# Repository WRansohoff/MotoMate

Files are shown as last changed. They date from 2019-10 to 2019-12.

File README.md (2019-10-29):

# "MotoMate" Handheld GPS Receiver

This is a small board designed to act as a handheld GPS receiver, and eventually (I hope) a handlebar-mounted GPS mapper / tracker for offroad motorcycling.

# Details

The microcontroller core is an STM32L496Rx chip - I recommend the STM32L496RGT3, because it costs less than $1 to get an extra 512KB of Flash (although the chip itself is more like $10). The 320KB of built-in RAM is enough to store a 150KB framebuffer for the 320x240 16bpp ILI9341 display, but it doesn't leave much room for storage-intensive algorithms such as image processing. Still, there's no external storage to worry about besides the microSD card.

The board is wired to use hardware periphererals for driving the SD/MMC interface, USB OTG, SPI for the display, and UART for talking to a "GY-NEO6MV2" GPS module. I've noticed that some listings for these u-blox Neo-6M-based GPS modules have red-colored boards with pinouts that won't work with this design; look for blue-colored ones and double-check the pinouts against the schematic. I might update the design to use the module itself instead of a cheap breakout board in the future, but for now, sorry for the inconvenience.

There's also a single-channel audio amplifier connected to one of the chip's DACs with a mute switch, and some ADCs are used to monitor a photodiode and the board's battery voltage. And there are pads exposed for an extra UART and I2C connection, and seven button inputs split across two tactile buttons and a 'navigation switch'. The buttons are assigned to pins so that there shouldn't be any conflicts with EXTI lines when setting up interrupts to listen for presses.

I'll write up more comprehensive information (and upload some proper gerber files) once I've had a chance to test this revision and upload some basic test firmwares to confirm the board's various functions.

# Schematic and Board Renders

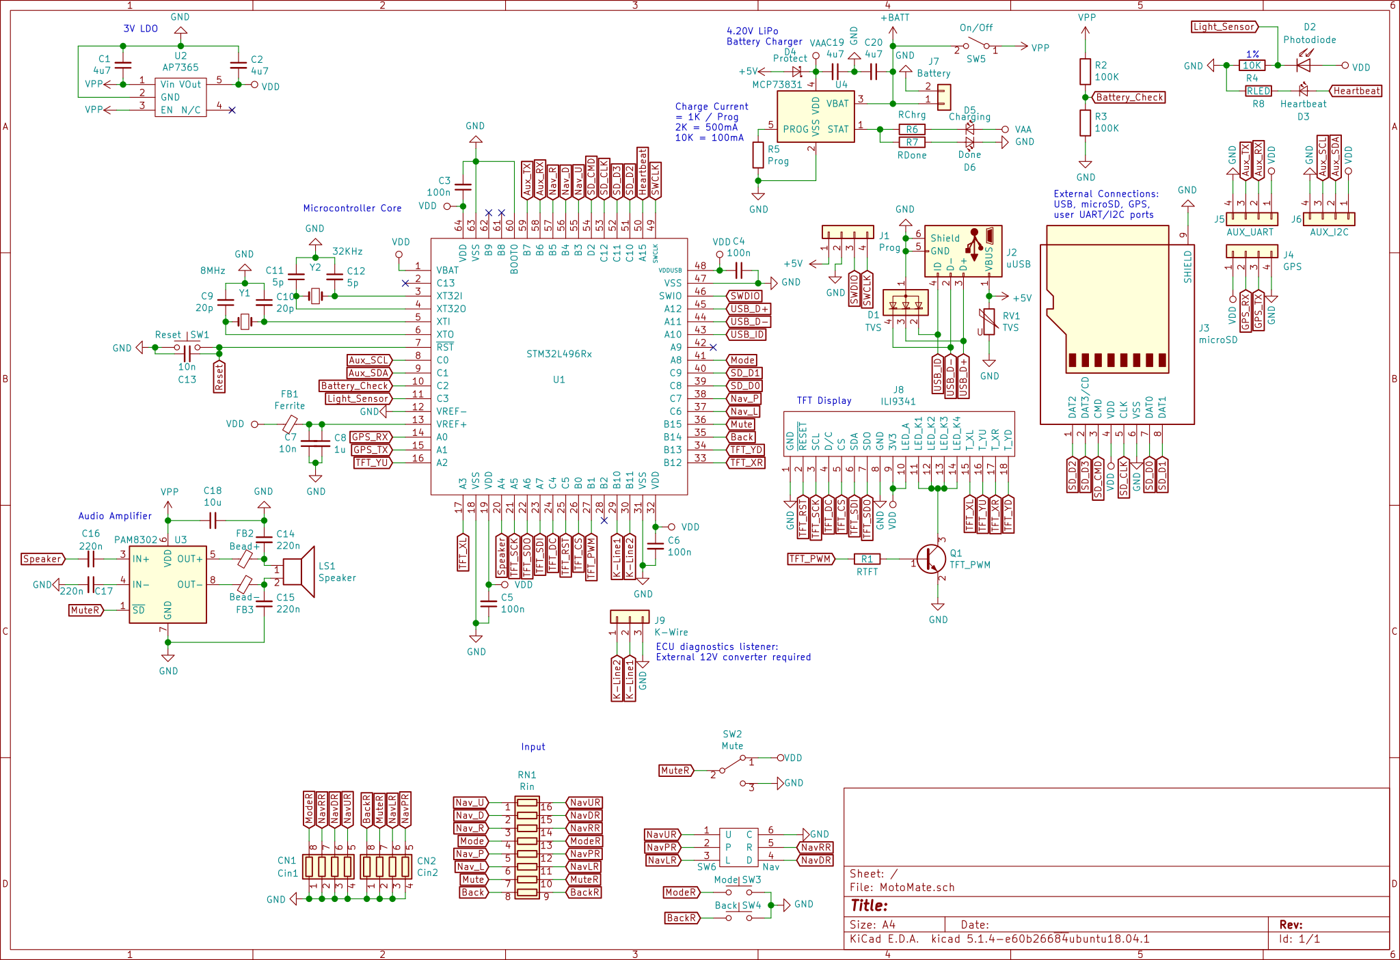
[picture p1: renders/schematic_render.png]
Schematic


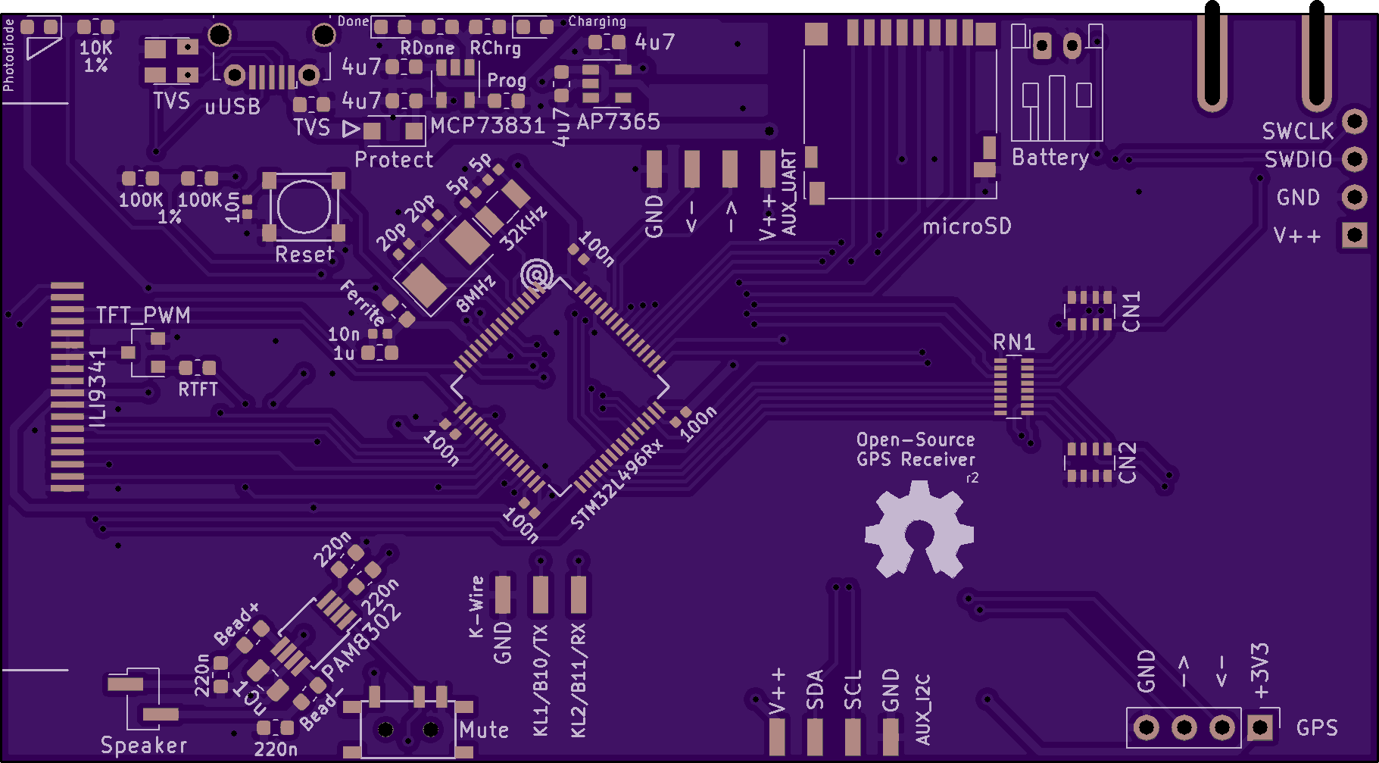
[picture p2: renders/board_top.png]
Board Top


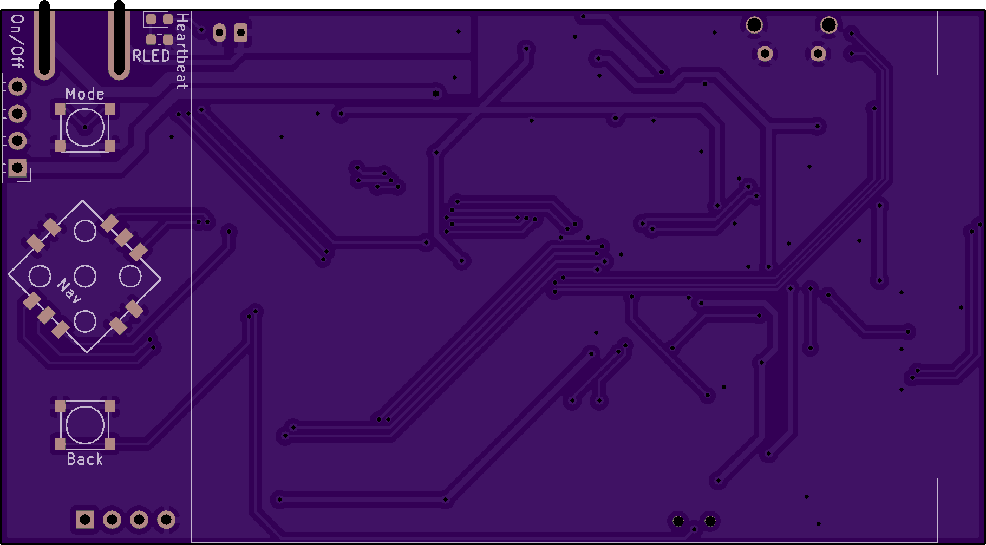
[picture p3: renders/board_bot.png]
Board Bottom


# Previous Revision

I've assembled an earlier version of this design and confirmed that most parts of the design work, but I haven't written a comprehensive "GPS mapper" firmware yet. The first version has too much space between the TFT ribbon connector and the edge of the board to fold the display over the USB connector and mute switch, so it was awkward to handle. I hope that this version will fit together better, but I haven't received it yet for testing.

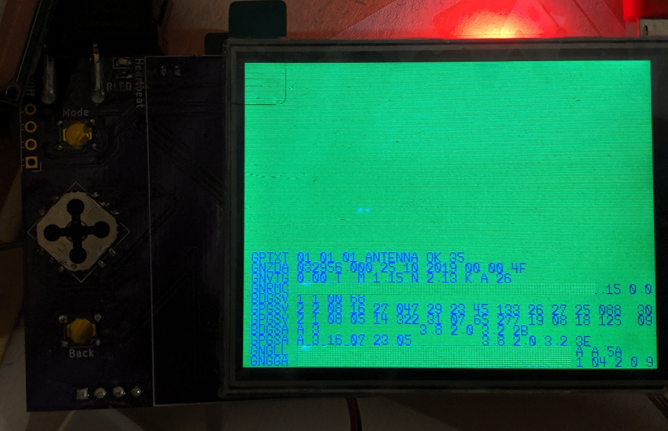
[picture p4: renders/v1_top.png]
V1 Top


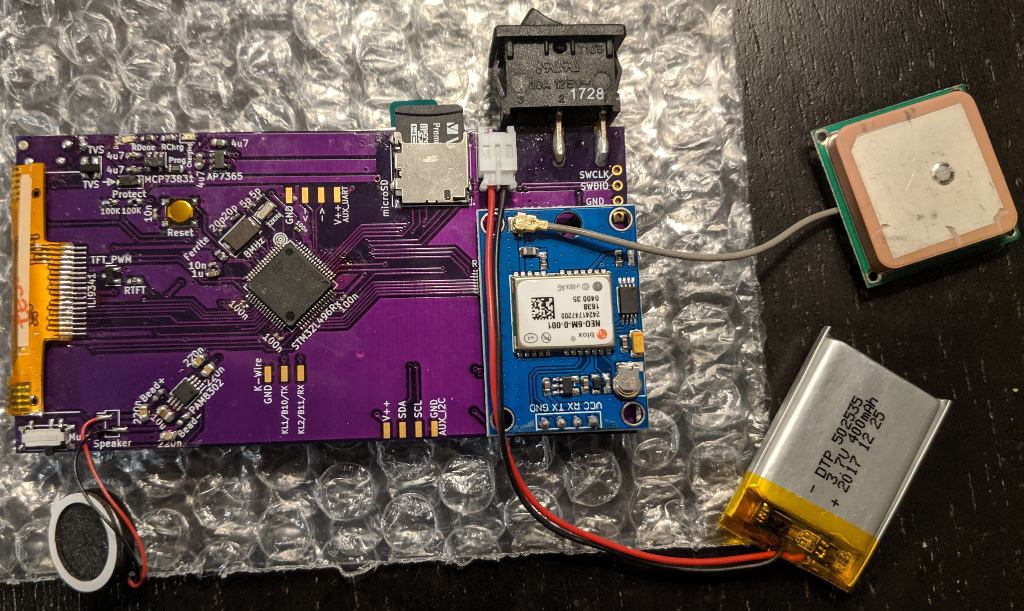
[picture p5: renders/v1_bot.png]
V1 Bottom


Sorry that I didn't get a better picture of the lit-up TFT; it's hard to take pictures of backlit displays, and it's not that important anyways. I also edited one of the images to remove the actual GPS coordinates, because I didn't feel like driving out to the middle of the woods to take a picture.

Anyways, so far I've tested (or not) the following parts:

* Battery monitoring: the 'charging' and 'done' LEDs seem to reflect the charge status, and the 12-bit ADC reads close to 4.2V on a full charge using the formula: `VBatt = ( ADC * 2 / 4095 ) * 3.3`. Note that for an accurate reading, you need to set one of the highest sampling times (250-650 cycles) due to the low amount of current flowing through the voltage divider.

* TFT display: The backlight can be adjusted with a PWM signal, and the SPI peripheral can be used with DMA to draw a framebuffer to the display. This makes it much easier to test other parts of the board :)

* GPS module: Appears to work, although I haven't tried configuring it with anything other than the default settings. After placing the antenna with a clear view of the sky and letting it acquire a few satellites, it reports latitude and longitude readings that appear to be accurate to within maybe 5 meters or so.

* microSD card: Not tested.

* Buttons: Tested using falling-edge interrupts with the pins configured as inputs with pull-up resistors enabled. These low-profile buttons are really designed to be used with a case that has plastic or rubber 'pegs' connected to larger buttons, though.

* Auxiliary UARTs and I2C: Not tested.

* 'Heartbeat' LED: Works.

* Photodiode: Not tested; in the first revision of the board, I put the photodiode underneath where the display's ribbon connector folded over, so it was always in darkness. D'oh!

* Speaker: Works well enough to play a sine wave accurately enough for a tuner to read the desired note. I haven't tried playing music or speech though, and it probably wouldn't do that very well. This is only a 12-bit DAC with poor filtering, after all. The speaker is mostly intended for beeps, buzzes, and chirps.

See `firmware/` for the source code used to run those tests, and `fw_lib/` for some shared helper functions.

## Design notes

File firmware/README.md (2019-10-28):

# Test Firmwares

These projects test various parts of the board. The directories are named after the functionality that a project tests. These use shared functionality from the libraries located under `../fw_lib/`.

The `v1_testsuite` project is an attempt to pull all of these examples into one firmware image which lets the user test each part of the board from a menu, although that will depend on the display and buttons working. It's a work-in-progress, but so is this entire repository.

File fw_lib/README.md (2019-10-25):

# Firmware Libraries

These directories include simple supporting libraries for parts that are mounted to the board. It might be re-inventing the wheel a bit, but these simple files should at least be enough to test that the board works.

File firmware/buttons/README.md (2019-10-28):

# Buttons Test

This project initializes the display, and sets up hardware interrupts for each of the 7 buttons. When a button is pressed, the display's background color will be changed.

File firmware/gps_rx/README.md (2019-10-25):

# GPS Reception Test

This project initializes the display and the UART connected to the GPS module, and draws the NMEA data received from the GPS module to the display. It's hard to read the raw data, but once enough satellites are acquired, it should print out the latitude and longitude in a fairly easy-to-parse format.

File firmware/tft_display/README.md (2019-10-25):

# TFT Framebuffer Test

This project tests using DMA and SPI to draw a framebuffer to the TFT display. It tests the various framebuffer drawing method, and flashes back and forth between colors to get a feel for the refresh rate. It looks pretty responsive, but I don't have any numbers yet.

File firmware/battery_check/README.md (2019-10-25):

# Battery Check

This project verifies that the board can read its own battery voltage. It initializes the display and the appropriate ADC channel, then it reads the channel and prints the raw ADC value to the display.

# TODO

I need to add a 'draw float' method to my simple framebuffer library, so that the example can draw an estimated voltage instead of the raw ADC value.

`VBatt = ( ADC * 2 / 4095 ) * VReg`

Where `VBatt` is the battery voltage and `VReg` is the regulated supply voltage. `VReg` is probably 3.3V, but sometimes I use 3V.

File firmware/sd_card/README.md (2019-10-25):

# SD Card test

This project is still a work-in-progress; right now I think it just flashes the display between two colors.

I'd like for it to test the microSD card slot, but I'm not there yet.

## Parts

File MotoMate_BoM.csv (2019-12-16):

Part ID | Part type | Part size (Imperial) | Part value | Example Digikey Item | Cost (qty: x) | Comment
C1, C2, C19, C20 | Capacitor | 0603 | 4.7 μF | https://www.digikey.com/short/p2hdqt | $0.68 | Power supply decoupling capacitors for voltage regulator and battery charger. Use X5 or X7 ceramic capacitors rated for at least 6.3V (for 5V voltage inputs)
C3, C4, C5, C6 | Capacitor | 0402 | 100 nF | https://www.digikey.com/short/p2hrz2 | $0.40 | Decoupling capacitors for the microcontroller / etc. Prefer X5 or X7 ceramic capacitors.
C7, C13 | Capacitor | 0402 | 10 nF | https://www.digikey.com/short/p2hr54 | $0.20 | Decoupling capacitors for the reset button and analog voltage supply. Use X7 ceramic capacitors.
C8 | Capacitor | 0603 | 1 μF | https://www.digikey.com/short/pdhnbv | $0.10 | Decoupling capacitor for the analog voltage supply. Use X7 ceramic capacitors.
C9, C10 | Capacitor | 0402 | 20 pF | https://www.digikey.com/short/pdhnbj | $0.20 | Decoupling capacitors for the high-speed external oscillator crystal. Actual values will depend on your crystal; 20pF is a rough estimate. Use C0G / NP0 ceramic capacitors.
C11, C12 | Capacitor | 0402 | 5 pF | https://www.digikey.com/short/pdhnbc | $0.20 | Decoupling capacitors for the low-speed external oscillator crystal. Actual values will depend on your crystal; 5pF is a rough estimate. Use C0G / NP0 capacitors.
C16, C17 | Capacitor | 0603 | 220 nF | https://www.digikey.com/short/pdhnhv | $0.20 | Filtering capacitors for the audio amplifier's input and output. Use X7 ceramic capacitors.
C18 | Capacitor | 0805 | 10 μF | https://www.digikey.com/short/pdhn55 | $0.13 | Power supply decoupling capacitor for the audio amplifier. Use X5 or X7 ceramic capacitors.
CN1, CN2 | Capacitor Network | 0612 | 10 nF | https://www.digikey.com/short/pdhr2m | $0.64 | Capacitor arrays for various debouncing filters. Values aren't too important; it's just to help prevent the microcontroller from incorrectly registering spurious button presses.
D1 | TVS Diode Network | SOT-143-4 | SP0503 | https://www.digikey.com/short/pdhfqd | $0.82 | 3-in-1 TVS diodes for USB data line filtering. These diodes should protect the two differential data lines and the OTG 'ID' line.
D2 | Photodiode | 0603 | ALS-PT19 | https://www.digikey.com/short/pdhfq3 | $0.43 | Photodiode for detecting ambient light levels. I hope this can be used for automatic brightness adjustment.
D3 | LED | 0603 | Any Color | https://www.digikey.com/short/p2hdpf | $0.14 | Heartbeat' LED, for basic testing and blinking.
D4 | Schottky Diode | SOD-123 | >= 10V, 1A | https://www.digikey.com/short/pdhw7b | $0.33 | Schottky diode to protect against reverse polarity.
D5 | LED | 0603 | Red | https://www.digikey.com/short/pdh21f | $0.14 | "Charging" LED, lit up when the battery is charging.
D6 | LED | 0603 | Green | https://www.digikey.com/short/pdh21m | $0.14 | "Done" LED, lit up when the battery has finished charging.
FB1 | Ferrite Bead | 0603 | N/A | https://www.digikey.com/short/p2h080 | $0.10 | Ferrite bead for filtering noise out of the analog voltage supply.
FB2, FB3 | Ferrite Bead | 0603 | N/A | https://www.digikey.com/short/p2h080 | $0.20 | Ferrite beads for filtering the audio amplifier's differential output.
J1 | Pin Header | 0.1" | 1x4 | https://www.digikey.com/short/pdhw3q | $0.13 | Programming / debugging header.
J2 | USB Connector | Micro-B Socket | N/A | https://www.digikey.com/short/pdhw81 | $2.07 | Micro-USB connector for battery charging and USB communication. I'm still working through a reel of cheap-o micro-B sockets that I ordered awhile ago, but they seem to fit the "Wuerth_629105150521" footprint in KiCAD.
J3 | MicroSD Connector | Socket | Hirose DM3D-SF | https://www.digikey.com/short/pdh2z2 | $1.75 | MicroSD card socket, for storing maps / images / routes / logs / etc.
J4 | Pin Header | 0.1" | 1x4 | https://item.taobao.com/item.htm?id=40580284168 | $2.50 | GPS breakout connector for a generic 4-pin uBlox Neo-6m GPS breakout board. This project is designed to fit a blue-colored "GY-NEO6MV2" breakout board, which is a cheap module that is widely available on eBay / Amazon / AliExpress / TaoBao / etc. These modules are much cheaper from Eastern listings than from Western ones. I've noticed that red-colored versions of this GPS module seem to have a different pinout that won't fit, so double-check the module's silkscreen markings against this project's schematic before you order one. Sorry that I can't link to a more reliable source; I can't endorse any particular third-party marketplace seller, including the one linked to here, and ordering from eBay-style sellers is never a completely sure bet. Maybe in the future I'll try to integrate the ublox module itself on the board.
J5, J6 | Pin Header | 0.1" | 1x4 | N/A | $0.00 | Flat single-side connectors for auxiliary UART and I2C add-ons. Optional.
J7 | JST Connector | PH-2 | 1x2 | https://www.digikey.com/short/pdh24c | $0.17 | Battery connector - the JST PH-2 connector is popular among small lithium batteries, such as those sold by Adafruit. Double-check the polarity!
J8 | Flex Ribbon Connector | 0.8 mm | 1x18 | https://item.taobao.com/item.htm?id=540901079780 | $3.33 | Connector for an 18-pin / 0.8mm-pitch 2.8" ILI9341 SPI TFT display with a resistive 'touch screen' overlay. These are cheap and widely-available from places like eBay / AliExpress / TaoBao / etc. DigiKey doesn't carry them, but using surplus 'off-brand' displays often saves about $10-20 per board for us hobbyists. Double-check the pinout against the listing you buy from, and consider using a different vendor or a forwarding service if you aren't familiar with ordering from TaoBao.
J9 | Pin Header | 0.1" | 1x3 | N/A | $0.00 | Flat single-side 3-pin connector for adding a "K-Wire" interface board later on. My motorcycle uses this old standard which predates OBD-II, and while it is a 12V single-wire protocol, I hope to eventually make an adapter board which isolates 'transmit' and 'receive' signals for use with a UART peripheral.
LS1 | Speaker | 2-Wire | 4 Ω | https://www.digikey.com/short/pdhnmp | $2.35 | Speaker for the single-channel audio amplifier output.
Q1 | Transistor | SOT-23 | NPN, BEC | https://www.digikey.com/short/pdhf4v | $0.12 | Transistor to control the TFT display's backlight brightness using PWM.
R1 | Resistor | 0603 | 1 KΩ | https://www.digikey.com/short/p2hdw9 | $0.10 | Base resistor for the TFT backlight control transistor. Value doesn't matter too much, keep it in the range of about 100Ω - 10KΩ
R2, R3 | Resistor | 0603 | 100 KΩ, 1% | https://www.digikey.com/short/pdh2b7 | $0.10 | Resistors for the voltage divider which lets the microcontroller read its own battery voltage. Use resistors with 1% precision, or choose two which have almost identical values.
R4 | Resistor | 0603 | 10 KΩ | https://www.digikey.com/short/pdh29r | $0.10 | Resistor which lets the microcontroller read an analog voltage from its photodiode input. Prefer resistors with 1% precision, but you'll probably have to calibrate the brightness reading anyways since photodiodes aren't very precise.
R5 | Resistor | 0603 | >= 2 KΩ, 1% | https://www.digikey.com/short/pdh2b4 | $0.10 | This resistor sets the rate of charge for the battery charger. Charge current = 1000 / R, so use 2KΩ for a 500mA charge rate, 10KΩ for a 100mA charge rate, etc. 500mA is the maximum charge rate. Use resistors with 1% precision to ensure you get the right charge rate.
R6, R7, R8 | Resistor | 0603 | 220Ω - 4.7KΩ | https://www.digikey.com/short/p2hdw9 | $0.30 | Current-limiting resistors for the "charging", "done charging", and "heartbeat" LEDs. Use higher values to make the LEDs dimmer.
RN1 | Resistor Network | 1506 | 1 KΩ | https://www.digikey.com/short/pdhr1z | $0.29 | Resistor array for various debouncing filters. Value isn't too important; it's just to help prevent the microcontroller from reading spurious button presses.
RV1 | Varistor | 0603 | 5.5V (7.1V-9.3V) | https://www.digikey.com/short/pdhrv3 | $0.48 | TVS varistor for the +5V power line. It should serve a similar function to the TVS diodes on the data lines, protecting the system from Transient Voltage surges.
SW1 | Tactile Button | SMD | SPST | https://www.digikey.com/short/pdhr0w | $0.22 | Reset button.
SW2, SW5 | Slide Switch | SMD | SPDT | https://www.digikey.com/short/pd2qtz | $1.82 | "Mute" switch for the speaker, and power on/off switch.
SW3, SW4 | Tactile Button | SMD | SPST | https://www.digikey.com/short/pdhr0w | $0.44 | "Mode" and "Back" tacticle buttons (user input).
SW6 | Navigation Switch | SMD | 5-Direction | https://www.digikey.com/short/pdhr0h | $2.38 | "Navigation switch" for user input. It has four directional buttons and one "press" button, plus a common pin which I connected to ground.
U1 | Microcontroller | QFP-64 (10x10 mm) | STM32L496 | https://www.digikey.com/short/pdhrd8 | $10.99 | Microcontroller core. The STM32L496Rx is available with either 512KB or 1MB of Flash memory. "-T6" suffix is rated to 85C, "-T3" to 125C. The 1MB / 125C version is less than $1 more expensive than the 512KB / 85C one, so I linked to the better one.
U2 | Voltage Regulator | DFN-6 (2x2 mm) | LDFM33 | https://www.digikey.com/short/p1r27t | $0.75 | Main voltage regulator.
U3 | Audio Amplifier | MSOP-8 (3x3 mm) | PAM8302A | https://www.digikey.com/short/pdhwt9 | $0.63 | Simple 2.5W mono audio amplifier. Mostly just for beeping and buzzing.
U4 | Battery Charger | SOT-25 | MCP73831 | https://www.digikey.com/short/pdhw7v | $0.56 | Battery charging circuit. I use the 4.2V version with "3.7V nominal / 4.2V charge" lithium batteries.
Y1 | Crystal | 5x3.2 mm | 8 MHz | https://www.digikey.com/short/pdhr1d | $1.14 | "High-Speed External" oscillator crystal. You can use values between 4MHz and 32MHz, but I usually use 8MHz.
Y2 | Crystal | 3.2x1.5 mm | 32.768 KHz | https://www.digikey.com/short/p2h0zh | $0.41 | "Low-Speed External" oscillator crystal.
Total: |  |  |  |  | $38.28 | You can shave a decent amount off this price by using generic connectors / crystals / etc, and by buying capacitors / resistors / diodes / etc in bulk. Just be sure to verify the footprints.

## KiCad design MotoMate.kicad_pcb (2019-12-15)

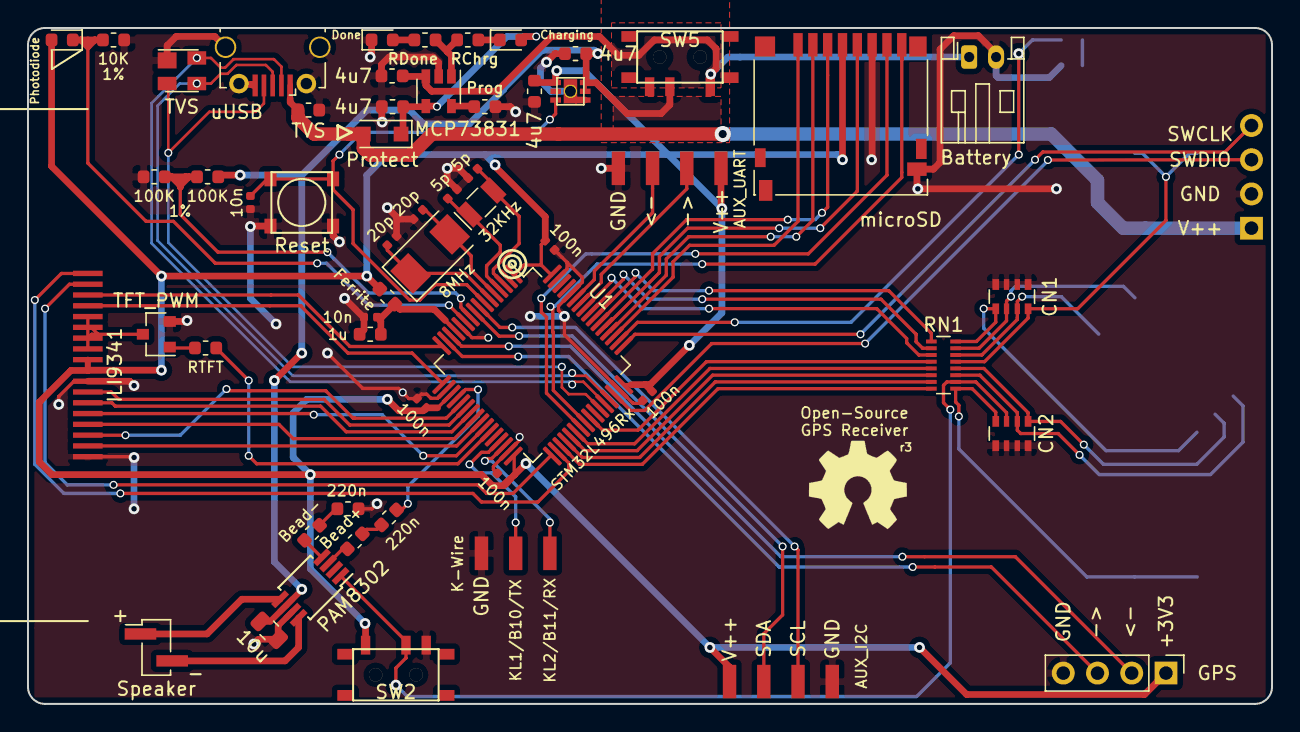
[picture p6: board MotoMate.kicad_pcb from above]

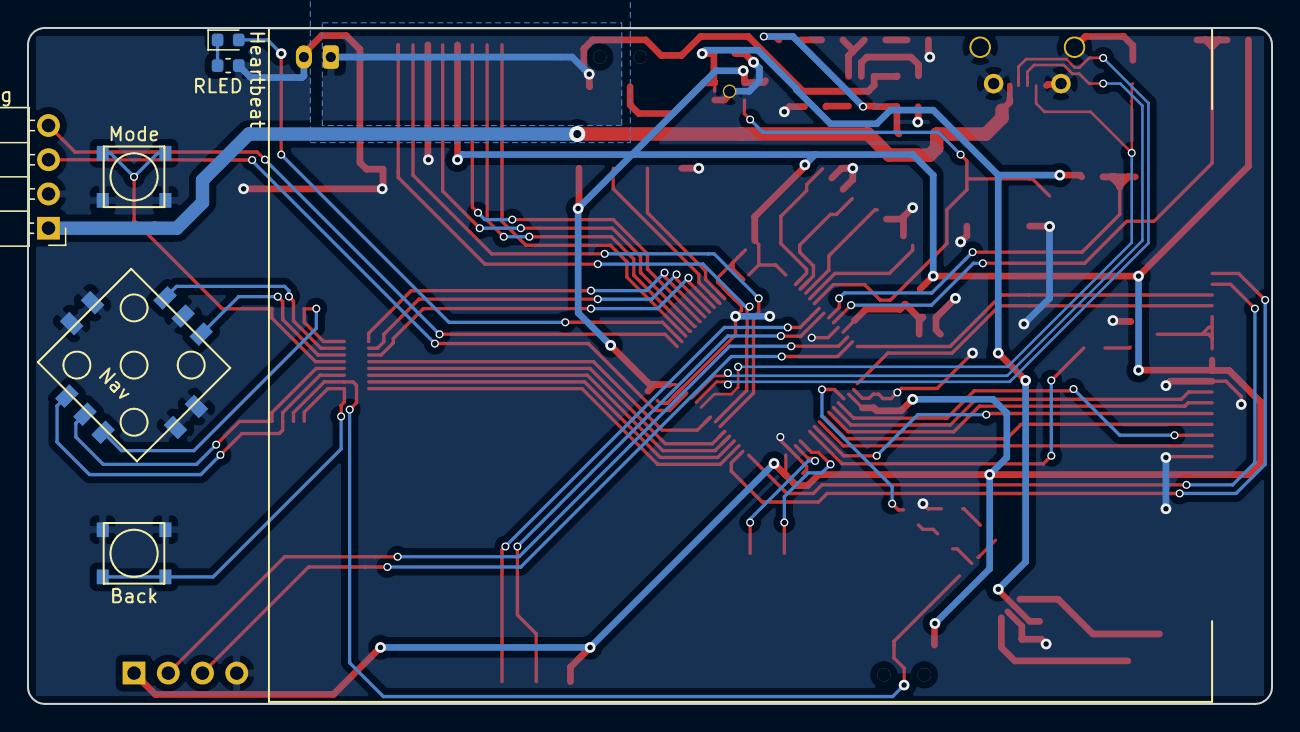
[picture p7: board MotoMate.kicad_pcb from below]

Board: 2 copper layers, 92.3 x 50.2 mm, 62 parts (6 on the bottom side), 75 nets.

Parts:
C1, C2, C19, C20: 4u7; C_0603_1608Metric
C3, C4, C5, C6: 100n; C_0402_1005Metric
C7, C13: 10n; C_0402_1005Metric
C8: 1u; C_0603_1608Metric
C9, C10: 20p; C_0402_1005Metric
C11, C12: 5p; C_0402_1005Metric
C16, C17: 220n; C_0603_1608Metric
C18: 10u; C_0805_2012Metric
CN1: Cin1; R_Array_Convex_4x0603
CN2: Cin2; R_Array_Convex_4x0603
D1: TVS; SOT-143
D2: Photodiode; LED_0603_1608Metric
D3: Heartbeat; LED_0603_1608Metric
D4: Protect; D_SOD-123F
D5: Charging; LED_0603_1608Metric
D6: Done; LED_0603_1608Metric
FB1: Ferrite; R_0603_1608Metric
FB2: Bead+; R_0603_1608Metric
FB3: Bead-; R_0603_1608Metric
J1: Prog; PinHeader_1x04_P2.54mm_Horizontal
J2: uUSB; MyMicroUSB
J3: microSD; microSD_HC_Hirose_DM3D-SF
J4: GPS; PinHeader_1x04_P2.54mm_Vertical
J5: AUX_UART; Conn_01x04_H_SMD
J6: AUX_I2C; Conn_01x04_H_SMD
J7: Battery; JST_PH_S2B-PH-K_1x02_P2.00mm_Horizontal
J8: ILI9341; ILI9341_18P_0.8mm
J9: K-Wire; Conn_01x03_H_SMD
LS1: Speaker; PinHeader_1x02_P2.00mm_Vertical_SMD_Pin1Left
Q1: TFT_PWM; SOT-23
R1: RTFT; R_0603_1608Metric
R2, R3: 100K; R_0603_1608Metric
R4: 10K; R_0603_1608Metric
R5: Prog; R_0603_1608Metric
R6: RChrg; R_0603_1608Metric
R7: RDone; R_0603_1608Metric
R8: RLED; R_0603_1608Metric
RN1: Rin; R_Array_Convex_8x0602
RV1: TVS; R_0603_1608Metric
SW1: Reset; Snap_Tac_Switch_SMT
SW2: Mute; mini_slide_switch
SW3: Mode; Snap_Tac_Switch_SMT
SW4: Back; Snap_Tac_Switch_SMT
SW5: On/Off; mini_slide_switch
SW6: Nav; NavSwitch_SMT
U1: STM32L496Rx; LQFP-64_10x10mm_P0.5mm
U2: LDFM33; ST_LDFM_2x2DFN
U3: PAM8302; MSOP-8_3x3mm_P0.65mm
U4: MCP73831; SOT-23-5
Y1: 8MHz; Crystal_SMD_Abracon_ABM3-2Pin_5.0x3.2mm
Y2: 32KHz; Crystal_SMD_EuroQuartz_EQ161-2Pin_3.2x1.5mm

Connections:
+5V: D4.2, J1.1, J2.1, RV1.1
+BATT: C20.1, J7.1, SW5.1, U4.3
Aux_RX: J5.2, U1.58
Aux_SCL: J6.3, U1.8
Aux_SDA: J6.2, U1.9
Aux_TX: J5.3, U1.59
Back: RN1.8, U1.35
BackR: CN2.8, RN1.9, SW4.1
Battery_Check: R2.1, R3.2, U1.10
GND: C1.2, C2.1, C3.2, C4.1, C5.1, C6.2, C7.1, C8.2, C9.2, C10.1, C11.2, C12.1, C13.2, C17.2, C18.2, C19.1, C20.2, CN1.1, CN1.2, CN1.3, CN1.4, CN2.1, CN2.2, CN2.3, CN2.4, D1.1, D6.1, J1.2, J2.5, J2.6, J3.6, J3.9, J4.4, J5.4, J6.4, J7.2, J8.1, J8.8, J9.3, Q1.2, R3.1, R4.2, R5.2, R8.2, RV1.2, SW1.1, SW2.3, SW3.2, SW4.2, SW6.6, U1.12, U1.18, U1.31, U1.47, U1.60, U1.63, U2.4, U2.7, U3.7, U4.2
GPS_RX: J4.2, U1.14
GPS_TX: J4.3, U1.15
Heartbeat: D3.2, U1.50
K-Line1: J9.2, U1.29
K-Line2: J9.1, U1.30
Light_Sensor: D2.1, R4.1, U1.11
Mode: RN1.4, U1.41
ModeR: CN1.8, RN1.13, SW3.1
Mute: RN1.7, U1.36
MuteR: CN2.7, RN1.10, SW2.2, U3.1
NavDR: CN1.6, RN1.15, SW6.4
NavLR: CN2.6, RN1.11, SW6.3
NavPR: CN2.5, RN1.12, SW6.2
NavRR: CN1.7, RN1.14, SW6.5
NavUR: CN1.5, RN1.16, SW6.1
Nav_D: RN1.2, U1.56
Nav_L: RN1.6, U1.37
Nav_P: RN1.5, U1.38
Nav_R: RN1.3, U1.57
Nav_U: RN1.1, U1.55
unnamed: C7.2, C8.1, FB1.1, U1.13
unnamed: C9.1, U1.6, Y1.1
unnamed: C10.2, U1.5, Y1.2
unnamed: C11.1, U1.4, Y2.1
unnamed: C12.2, U1.3, Y2.2
unnamed: C16.1, FB2.2
unnamed: C17.1, FB3.1
unnamed: D3.1, R8.1
unnamed: D5.1, R6.1
unnamed: D6.2, R7.1
unnamed: FB2.1, U3.3
unnamed: FB3.2, U3.4
unnamed: J8.11, J8.12, J8.13, J8.14, Q1.3
unnamed: LS1.1, U3.5
unnamed: LS1.2, U3.8
unnamed: Q1.1, R1.1
unnamed: R5.1, U4.5
unnamed: R6.2, R7.2, U4.1
Reset: C13.1, SW1.2, U1.7, U2.3
SD_CLK: J3.5, U1.53
SD_CMD: J3.3, U1.54
SD_D0: J3.7, U1.39
SD_D1: J3.8, U1.40
SD_D2: J3.1, U1.51
SD_D3: J3.2, U1.52
SWCLK: J1.4, U1.49
SWDIO: J1.3, U1.46
Speaker: C16.2, U1.20
TFT_CS: J8.5, U1.26
TFT_DC: J8.4, U1.24
TFT_PWM: R1.2, U1.27
TFT_RST: J8.2, U1.25
TFT_SCK: J8.3, U1.21
TFT_SDI: J8.6, U1.23
TFT_SDO: J8.7, U1.22
TFT_XL: J8.15, U1.17
TFT_XR: J8.17, U1.33
TFT_YD: J8.18, U1.34
TFT_YU: J8.16, U1.16
USB_D+: D1.3, J2.3, U1.45
USB_D-: D1.4, J2.2, U1.44
USB_ID: D1.2, J2.4, U1.43
VAA: C19.2, D4.1, D5.2, U4.4
VDD: C1.1, C3.1, C4.2, C5.2, C6.1, D2.2, FB1.2, J3.4, J4.1, J5.1, J6.1, J8.9, J8.10, SW2.1, U1.1, U1.19, U1.32, U1.48, U1.64, U2.1
VPP: C2.2, C18.1, R2.2, SW5.2, U2.5, U2.6, U3.6

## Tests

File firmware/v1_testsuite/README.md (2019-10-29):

# Test Suite, Version 1

This project initializes every part of the board, and displays a menu which lets the user perform various tests.

Currently, it has a main menu and a few different options. The 'back' button returns to the main menu from each individual test, and unused buttons will sometimes change the background and text color. Currently only the 'view raw GPS messages' test works, and the other parts are works-in-progress.

It won't actually test every part of the board for a little while, since I haven't done anything with the USB plug or the SD card interface, but those are on the to-do list.

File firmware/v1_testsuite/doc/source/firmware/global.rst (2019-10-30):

Global application values
=========================

These variables and preprocessor definitions are used throughout the entire application. For the most part, they are statically-allocated resources dedicated to individual board functions such as the display or audio output.

.. c:autodoc:: src/global.h

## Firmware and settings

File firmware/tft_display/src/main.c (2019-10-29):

// Standard library includes.
#include <stdint.h>
#include <stdlib.h>
// Vendor-provided device header file.
#include "stm32l4xx.h"
// HAL includes.
#include "hal/dma.h"
#include "hal/gpio.h"
#include "hal/rcc.h"
#include "hal/spi.h"
#include "hal/tim.h"
// BSP includes.
#include "ili9341.h"
#include "ufb.h"

// Dummy 'current audio samples' value for HAL library.
volatile int cur_samples = 32;

// 320x240-pixel 16-bit (RGB-565) framebuffer. Note: it's 150KB of RAM
uint16_t FRAMEBUFFER[ ILI9341_A ];
uFB framebuffer = {
  w: ILI9341_W,
  h: ILI9341_H,
  buf: ( uint16_t* )&FRAMEBUFFER
};

// Global variable to hold the core clock speed in Hertz.
uint32_t SystemCoreClock = 4000000;

/**
 * Main program.
 */
int main(void) {
  // Initialize the core clock speed to 80MHz.
  clock_init();

  // Enable peripherals: GPIOA, GPIOB, GPIOC, DMA1, SPI1, TIM3.
  RCC->AHB1ENR  |= ( RCC_AHB1ENR_DMA1EN );
  RCC->AHB2ENR  |= ( RCC_AHB2ENR_GPIOAEN |
                     RCC_AHB2ENR_GPIOBEN |
                     RCC_AHB2ENR_GPIOCEN );
  RCC->APB1ENR1 |= ( RCC_APB1ENR1_TIM3EN );
  RCC->APB2ENR  |= ( RCC_APB2ENR_SPI1EN );

  // Setup the NVIC hardware interrupts.
  // Use 4 bits for 'priority' and 0 bits for 'subpriority'.
  NVIC_SetPriorityGrouping( 0x00 );
  // DMA interrupts should be high-priority. (0 is highest)
  uint32_t dma_pri_encoding = NVIC_EncodePriority( 0x00, 0x01, 0x00 );
  NVIC_SetPriority( DMA1_Channel3_IRQn, dma_pri_encoding );
  NVIC_EnableIRQ( DMA1_Channel3_IRQn );

  // Setup GPIO pin(s).
  // PB1: Alt. Func. #2 (TIM3_CH4), low-speed.
  gpio_af_setup( GPIOB, 1, 2, 0 );
  // PB0: Push-pull output (CS pin)
  gpio_setup( GPIOB, 0, GPIO_OUT_PP );
  gpio_hi( GPIOB, 0 );
  // PC5: Push-pull output (TFT Reset pin)
  gpio_setup( GPIOC, 5, GPIO_OUT_PP );
  gpio_hi( GPIOC, 5 );
  // PC4: Push-pull output (Data/Command pin)
  gpio_setup( GPIOC, 4, GPIO_OUT_PP );
  // PA5, PA6, PA7: Alt. Func. #5, mid-speed (SPI1 SCK/SDO/SDI)
  gpio_af_setup( GPIOA, 5, 5, 1 );
  gpio_af_setup( GPIOA, 6, 5, 1 );
  gpio_af_setup( GPIOA, 7, 5, 1 );
  // PA15: 'Heartbeat' LED. (Note: overrides JTDI debugging pin)
  gpio_setup( GPIOA, 15, GPIO_OUT_PP );
  gpio_lo( GPIOA, 15 );

  // Set Timer 3, Channel 4 to a PWM signal with 30% duty cycle.
  // Prescaler
  TIM3->PSC   = 0x0000;
  // Duty cycle = (CCR / ARR).
  TIM3->CCR4  = 3000;
  TIM3->ARR   = 10000;
  // Enable CCR output, set 'PWM mode 1'.
  TIM3->CCER  |=  ( TIM_CCER_CC4E );
  TIM3->CCMR2 &= ~( TIM_CCMR2_OC4M );
  TIM3->CCMR2 |=  ( 0x6 << TIM_CCMR2_OC4M_Pos );
  // Set 'update generation' bit, then start the timer.
  TIM3->EGR   |=  ( TIM_EGR_UG );
  TIM3->CR1   |=  ( TIM_CR1_CEN );

  // DMA configuration (DMA1, channel 3).
  // CCR register:
  // - Memory-to-peripheral
  // - Circular mode disabled.
  // - Increment memory ptr, don't increment periph ptr.
  // - 16-bit data size for both source and destination.
  // - High priority (2/3).
  // - Enable 'transfer complete' interrupt.
  DMA1_Channel3->CCR &= ~( DMA_CCR_MEM2MEM |
                           DMA_CCR_PL |
                           DMA_CCR_CIRC |
                           DMA_CCR_MSIZE |
                           DMA_CCR_PSIZE |
                           DMA_CCR_PINC |
                           DMA_CCR_EN );
  DMA1_Channel3->CCR |=  ( ( 0x2 << DMA_CCR_PL_Pos ) |
                           ( 0x1 << DMA_CCR_MSIZE_Pos ) |
                           ( 0x1 << DMA_CCR_PSIZE_Pos ) |
                           DMA_CCR_MINC |
                           DMA_CCR_TCIE |
                           DMA_CCR_DIR );
  // Set DMA channel selection to pick which of the preset
  // peripheral options we want to use.
  DMA1_CSELR->CSELR &= ~( DMA_CSELR_C3S );
  DMA1_CSELR->CSELR |=  ( 0x1 << DMA_CSELR_C3S_Pos );
  // Set DMA source and destination addresses.
  // Source: Address of the sine wave buffer in memory.
  DMA1_Channel3->CMAR  = ( uint32_t )&FRAMEBUFFER;
  // Dest.: SPI1 data register.
  DMA1_Channel3->CPAR  = ( uint32_t )&( SPI1->DR );
  // Set DMA data transfer length (# of bytes in the framebuffer).
  // TODO: We can't transfer the whole FB, since it is >64K words.
  // So, I'll need to set up a 'transfer complete' interrupt
  // to change the source address and restart the transfer.
  DMA1_Channel3->CNDTR = ( uint16_t )( ILI9341_A / 2 );

  // Setup SPI1 for communicating with the TFT.
  // - Clock phase/polarity: 1/1
  // - Assert internal CS signal (software CS pin control)
  // - MSB-first
  // - 8-bit frames
  // - Baud rate prescaler of 2 (or 128 for debugging)
  // - Enable TX DMA requests.
  SPI1->CR1 &= ~( SPI_CR1_LSBFIRST |
                  SPI_CR1_BR );
  SPI1->CR1 |=  ( SPI_CR1_SSM |
                  SPI_CR1_SSI |
                  0x0 << SPI_CR1_BR_Pos |
                  //0x7 << SPI_CR1_BR_Pos |
                  SPI_CR1_MSTR |
                  SPI_CR1_CPOL |
                  SPI_CR1_CPHA );
  SPI1->CR2 &= ~( SPI_CR2_DS );
  SPI1->CR2 |=  ( 0x7 << SPI_CR2_DS_Pos |
                  SPI_CR2_TXDMAEN );
  // Enable the SPI peripheral.
  SPI1->CR1 |=  ( SPI_CR1_SPE );

  // Send initialization commands.
  // Pull CS pin low.
  gpio_lo( GPIOB, 0 );
  // Software reset.
  dat_cmd( SPI1, ILI9341_CMD );
  spi_w8( SPI1, 0x01 );
  delay_cycles( 200000 );
  // Display off.
  spi_w8( SPI1, 0x28 );
  // Color mode: 16bpp.
  spi_w8( SPI1, 0x3A );
  dat_cmd( SPI1, ILI9341_DAT );
  spi_w8( SPI1, 0x55 );
  // Memory access control: flip display across the 240px axis.
  dat_cmd( SPI1, ILI9341_CMD );
  spi_w8( SPI1, 0x36 );
  dat_cmd( SPI1, ILI9341_DAT );
  spi_w8( SPI1, 0x40 );
  // Exit sleep mode.
  dat_cmd( SPI1, ILI9341_CMD );
  spi_w8( SPI1, 0x11 );
  delay_cycles( 200000 );
  // Display on.
  spi_w8( SPI1, 0x29 );
  delay_cycles( 200000 );
  // Set drawing window.
  // Column set: [0:239]
  spi_w8( SPI1, 0x2A );
  dat_cmd( SPI1, ILI9341_DAT );
  spi_w16( SPI1, 0x0000 );
  spi_w16( SPI1, ( ( 239 & 0xFF ) << 8 ) | ( 239 >> 8 ) );
  dat_cmd( SPI1, ILI9341_CMD );
  // Row set: [0:319]
  spi_w8( SPI1, 0x2B );
  dat_cmd( SPI1, ILI9341_DAT );
  spi_w16( SPI1, 0x0000 );
  spi_w16( SPI1, ( ( 319 & 0xFF ) << 8 ) | ( 319 >> 8 ) );
  dat_cmd( SPI1, ILI9341_CMD );
  // Set 'write to RAM' mode.
  spi_w8( SPI1, 0x2C );
  // From now on, we'll only be sending pixel data.
  dat_cmd( SPI1, ILI9341_DAT );

  // Enable DMA1 Channel 3.
  DMA1_Channel3->CCR |= ( DMA_CCR_EN );

  // Done; now just alternate between solid colors to get
  // a feel for the refresh speed.
  uint16_t color = rgb565( 0x1F, 0x00, 0x1F );
  uint16_t r_col = rgb565( 0x1F, 0x08, 0x00 );
  while (1) {
    // Draw the new color to the framebuffer.
    ufb_fill_rect( &framebuffer, color, 0, 0, 240, 320 );
    ufb_draw_rect( &framebuffer, ( color ^ 0xFFFF ), 0, 0, 240, 320, 4 );
    ufb_draw_circle( &framebuffer, ( color ^ 0xFFFF ), 120, 160, 30, 8 );
    ufb_fill_circle( &framebuffer, ( color ^ 0xFFFF ), 40, 40, 15 );
    ufb_fill_circle( &framebuffer, ( color ^ 0xFFFF ), 200, 260, 50 );
    ufb_draw_rect( &framebuffer, r_col, -5, 285, 50, 50, 6 );
    ufb_fill_circle( &framebuffer, ( color ^ 0xFFFF ), 20, 310, 25 );
    ufb_draw_str( &framebuffer, ( color ^ 0xFFFF ), 20, 20, "Hello\0", 2, UFB_ORIENT_H );
    ufb_draw_str( &framebuffer, ( color ^ 0xFFFF ), 15, 10, "Hello\0", 1, UFB_ORIENT_V );
    ufb_draw_str( &framebuffer, r_col, 180, 30, "Test\0", 7, UFB_ORIENT_H );
    //ufb_fill_rect( &framebuffer, ( color ^ 0xFFFF ), 200, 20, 6, 8 );
    // Invert the color.
    color = color ^ 0xFFFF;
    // Delay briefly.
    delay_cycles( 5000000 );
    // Toggle the 'heartbeat' LED.
    //gpio_toggle( GPIOA, 15 );
  }
}

/* Interrupt Handlers */
// DMA1, Channel 3: SPI transmit.
void DMA1_chan3_IRQ_handler( void ) {
  // Since the DMA peripheral can only handle buffers up to 64KWords,
  // we can't sent the whole 75KWord framebuffer at once. So instead,
  // we send one half at a time and update the source address every
  // time that a 'transfer complete' interrupt triggers.
  if ( DMA1->ISR & DMA_ISR_TCIF3 ) {
    // Acknowledge the interrupt.
    DMA1->IFCR |=  ( DMA_IFCR_CTCIF3 );
    // Disable the DMA channel.
    DMA1_Channel3->CCR &= ~( DMA_CCR_EN );
    // Update the source address and refill the 'count' register.
    if ( DMA1_Channel3->CMAR >= ( uint32_t )&( FRAMEBUFFER[ ILI9341_A / 2 ] ) ) {
      DMA1_Channel3->CMAR  = ( uint32_t )&FRAMEBUFFER;
    }
    else {
      DMA1_Channel3->CMAR  = ( uint32_t )&( FRAMEBUFFER[ ILI9341_A / 2 ] );
    }
    DMA1_Channel3->CNDTR = ( uint16_t )( ILI9341_A / 2 );
    // Re-enable the DMA channel to resume the transfer.
    DMA1_Channel3->CCR |=  ( DMA_CCR_EN );
  }
}

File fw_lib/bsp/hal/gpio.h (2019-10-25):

/*
 * Minimal GPIO interface methods.
 */
#ifndef __VVC_GPIO
#define __VVC_GPIO

// Device header file.
#include "stm32l4xx.h"

// 'Quick initialization' tags
// TODO: enum?
#define GPIO_IN        ( 0 )
#define GPIO_IN_PU     ( 1 )
#define GPIO_IN_PD     ( 2 )
#define GPIO_OUT_PP    ( 3 )
#define GPIO_OUT_OD    ( 4 )
#define GPIO_OUT_OD_PU ( 5 )
#define GPIO_ANALOG    ( 6 )

/* Helper macros */
// Reset a GPIO pin's registers to 'floating input' state.
#define GPIO_CLEAR_PIN( GPIOx, p ) \
  GPIOx->OTYPER       &= ~( 0x1 << p ); \
  GPIOx->PUPDR        &= ~( 0x3 << ( p * 2 ) ); \
  GPIOx->OSPEEDR      &= ~( 0x3 << ( p * 2 ) ); \
  GPIOx->MODER        &= ~( 0x3 << ( p * 2 ) ); \
  GPIOx->AFR[ p / 8 ] &= ~( 0xF << ( ( p % 8 ) * 4 ) );
// Pull a GPIO pin high (if it has been configured as an output.)
#define gpio_hi( GPIOx, pin ) \
  GPIOx->BSRR |=  ( 1 << ( pin ) );
// Pull a GPIO pin low (if it has been configured as an output.)
#define gpio_lo( GPIOx, pin ) \
  GPIOx->BSRR |=  ( 1 << ( pin + 16 ) );
// Toggle a GPIO pin's output state (if it is in output mode.)
#define gpio_toggle( GPIOx, pin ) \
  GPIOx->ODR  ^=  ( 1 << pin );

// Setup a GPIO pin for normal use.
void gpio_setup( GPIO_TypeDef* GPIOx, int pin, int gpio_type );

// Setup a GPIO pin for 'alternate function' mode.
void gpio_af_setup( GPIO_TypeDef* GPIOx, int pin,
                    int af_num, int ospeed );

#endif

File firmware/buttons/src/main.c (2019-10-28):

// Standard library includes.
#include <stdint.h>
#include <stdlib.h>
// Vendor-provided device header file.
#include "stm32l4xx.h"
// HAL includes.
#include "hal/dma.h"
#include "hal/gpio.h"
#include "hal/rcc.h"
#include "hal/spi.h"
#include "hal/tim.h"
// BSP includes.
#include "ili9341.h"
#include "ringbuf.h"
#include "ufb.h"

// Dummy 'current audio samples' value for HAL library.
volatile int cur_samples = 32;

// 320x240-pixel 16-bit (RGB-565) framebuffer. Note: it's 150KB of RAM.
uint16_t FRAMEBUFFER[ ILI9341_A ];
uFB framebuffer = {
  w: ILI9341_W,
  h: ILI9341_H,
  buf: ( uint16_t* )&FRAMEBUFFER
};

// Solid color to set the display to; button presses will change this.
volatile uint16_t color = rgb565( 0x1F, 0x00, 0x1F );

// Global variable to hold the core clock speed in Hertz.
uint32_t SystemCoreClock = 4000000;

/**
 * Main program.
 */
int main(void) {
  // Initialize the core clock speed to 80MHz.
  clock_init();

  // Enable peripherals: GPIOA, GPIOB, GPIOC,
  // DMA1, SPI1, TIM3, SYSCFG.
  RCC->AHB1ENR  |=  ( RCC_AHB1ENR_DMA1EN );
  RCC->AHB2ENR  |=  ( RCC_AHB2ENR_GPIOAEN |
                      RCC_AHB2ENR_GPIOBEN |
                      RCC_AHB2ENR_GPIOCEN );
  RCC->APB1ENR1 |=  ( RCC_APB1ENR1_TIM3EN );
  RCC->APB2ENR  |=  ( RCC_APB2ENR_SPI1EN |
                      RCC_APB2ENR_SYSCFGEN );

  // Enable FPU. (Set Coprocessors 1 & 2 to 'full access')
  // Trying to use floats before this is called will cause a crash.
  SCB->CPACR    |=  ( 0xF << 20 );

  // Setup GPIO pin(s).
  // PB1: Alt. Func. #2 (TIM3_CH4), low-speed.
  gpio_af_setup( GPIOB, 1, 2, 0 );
  // PB0: Push-pull output (CS pin)
  gpio_setup( GPIOB, 0, GPIO_OUT_PP );
  gpio_hi( GPIOB, 0 );
  // PC5: Push-pull output (TFT Reset pin)
  gpio_setup( GPIOC, 5, GPIO_OUT_PP );
  gpio_hi( GPIOC, 5 );
  // PC4: Push-pull output (Data/Command pin)
  gpio_setup( GPIOC, 4, GPIO_OUT_PP );
  // PA5, PA6, PA7: Alt. Func. #5, mid-speed (SPI1 SCK/SDO/SDI)
  gpio_af_setup( GPIOA, 5, 5, 1 );
  gpio_af_setup( GPIOA, 6, 5, 1 );
  gpio_af_setup( GPIOA, 7, 5, 1 );
  // PA15: 'Heartbeat' LED. (Note: overrides JTDI debugging pin)
  gpio_setup( GPIOA, 15, GPIO_OUT_PP );
  gpio_lo( GPIOA, 15 );
  // Setup button pins as inputs with pull-up resistors enabled.
  // PB3, PB4, PB5, C6, C7: Navigation switch button inputs.
  gpio_setup( GPIOB, 3, GPIO_IN_PU );
  gpio_setup( GPIOB, 4, GPIO_IN_PU );
  gpio_setup( GPIOB, 5, GPIO_IN_PU );
  gpio_setup( GPIOC, 6, GPIO_IN_PU );
  gpio_setup( GPIOC, 7, GPIO_IN_PU );
  // PA8: 'Mode' button input.
  gpio_setup( GPIOA, 8, GPIO_IN_PU );
  // PB14: 'Back' button input.
  gpio_setup( GPIOB, 14, GPIO_IN_PU );

  // Enable EXTI interrupts for button pins.
  SYSCFG->EXTICR[ 0 ] &= ~( SYSCFG_EXTICR1_EXTI3_Msk );
  SYSCFG->EXTICR[ 0 ] |=  ( SYSCFG_EXTICR1_EXTI3_PB );
  SYSCFG->EXTICR[ 1 ] &= ~( SYSCFG_EXTICR2_EXTI4_Msk |
                            SYSCFG_EXTICR2_EXTI5_Msk |
                            SYSCFG_EXTICR2_EXTI6_Msk |
                            SYSCFG_EXTICR2_EXTI7_Msk );
  SYSCFG->EXTICR[ 1 ] |=  ( SYSCFG_EXTICR2_EXTI4_PB |
                            SYSCFG_EXTICR2_EXTI5_PB |
                            SYSCFG_EXTICR2_EXTI6_PC |
                            SYSCFG_EXTICR2_EXTI7_PC );
  SYSCFG->EXTICR[ 2 ] &= ~( SYSCFG_EXTICR3_EXTI8_Msk );
  SYSCFG->EXTICR[ 2 ] |=  ( SYSCFG_EXTICR3_EXTI8_PA );
  SYSCFG->EXTICR[ 3 ] &= ~( SYSCFG_EXTICR4_EXTI14_Msk );
  SYSCFG->EXTICR[ 3 ] |=  ( SYSCFG_EXTICR4_EXTI14_PB );
  // Enable interrupts for the given pins.
  EXTI->IMR1          |=  ( EXTI_IMR1_IM3 |
                            EXTI_IMR1_IM4 |
                            EXTI_IMR1_IM5 |
                            EXTI_IMR1_IM6 |
                            EXTI_IMR1_IM7 |
                            EXTI_IMR1_IM8 |
                            EXTI_IMR1_IM14 );
  // Disable 'rising edge' interrupts.
  EXTI->RTSR1         &= ~( EXTI_RTSR1_RT3 |
                            EXTI_RTSR1_RT4 |
                            EXTI_RTSR1_RT5 |
                            EXTI_RTSR1_RT6 |
                            EXTI_RTSR1_RT7 |
                            EXTI_RTSR1_RT8 |
                            EXTI_RTSR1_RT14 );
  // Enable 'falling edge' interrupts.
  EXTI->FTSR1         |=  ( EXTI_FTSR1_FT3 |
                            EXTI_FTSR1_FT4 |
                            EXTI_FTSR1_FT5 |
                            EXTI_FTSR1_FT6 |
                            EXTI_FTSR1_FT7 |
                            EXTI_FTSR1_FT8 |
                            EXTI_FTSR1_FT14 );

  // Setup the NVIC hardware interrupts.
  // Use 4 bits for 'priority' and 0 bits for 'subpriority'.
  NVIC_SetPriorityGrouping( 0x00 );
  // DMA interrupts should be high-priority. (0 is highest)
  uint32_t dma_pri_encoding = NVIC_EncodePriority( 0x00, 0x01, 0x00 );
  NVIC_SetPriority( DMA1_Channel3_IRQn, dma_pri_encoding );
  NVIC_EnableIRQ( DMA1_Channel3_IRQn );
  // Button inputs should be fairly low priority (15 is lowest)
  uint32_t btn_pri_encoding = NVIC_EncodePriority( 0x00, 0x0C, 0x00 );
  NVIC_SetPriority( EXTI3_IRQn, btn_pri_encoding );
  NVIC_EnableIRQ( EXTI3_IRQn );
  NVIC_SetPriority( EXTI4_IRQn, btn_pri_encoding );
  NVIC_EnableIRQ( EXTI4_IRQn );
  NVIC_SetPriority( EXTI9_5_IRQn, btn_pri_encoding );
  NVIC_EnableIRQ( EXTI9_5_IRQn );
  NVIC_SetPriority( EXTI15_10_IRQn, btn_pri_encoding );
  NVIC_EnableIRQ( EXTI15_10_IRQn );

  // Set Timer 3, Channel 4 to a 1MHz PWM signal with 30% duty cycle.
  timer_pwm_out( TIM3, 4, 0.3, 1000000 );

  // DMA configuration (DMA1, channel 3).
  dma_config_tx( DMA1_BASE, 3,
                 ( uint32_t )&FRAMEBUFFER,
                 ( uint32_t )&( SPI1->DR ),
                 ( uint16_t )( ILI9341_A / 2 ),
                 1, DMA_PRIORITY_HI, DMA_SIZE_16b, 0, 1 );

  // Setup SPI1 for communicating with the TFT.
  spi_host_init( SPI1, 0, 1 );

  // Send initialization commands to the display.
  ili9341_init( SPI1 );

  // Enable DMA1 Channel 3.
  DMA1_Channel3->CCR |= ( DMA_CCR_EN );

  // Done.
  while (1) {
    // Clear the display.
    ufb_fill_rect( &framebuffer, color, 0, 0, 240, 320 );
    // Delay briefly.
    delay_cycles( 50000 );
    // Toggle the 'heartbeat' LED.
    //gpio_toggle( GPIOA, 15 );
  }
}

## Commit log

2019-10-25 Add custom schematic symbols and footprints.
2019-10-25 Add Bill of Materials.
    [MotoMate_BoM.csv]
2019-10-25 Add project / schematic / PCB files.
    [MotoMate.kicad_pcb, MotoMate.sch]
2019-10-25 Round off a power trace that wound up with a weird 'elbow' shape somehow.
    [MotoMate.kicad_pcb]
2019-10-25 Add some simple supporting methods to configure peripherals for use with the board and interact with on-board devices.
2019-10-25 Add directories for not-yet-working test projects: buttons, SD card, and touch screen.
2019-10-25 Add test firmware to monitor the ADC channel connected to the battery voltage.
2019-10-25 Add test firmware for drawing to the TFT display through a DMA-ferried framebuffer.
2019-10-25 Add test firmware for listening to the GPS module and printing its raw output to the TFT display.
2019-10-26 Fix Makefiles to reflect the current directory structure.
2019-10-28 Minor comment fixes in the GPS test firmware.
    [interrupts.c, main.c]
2019-10-28 Add a simple firmware to test the button inputs.
2019-10-28 Add an outline of a combined 'test suite' firmware which will combine tests for different parts of the board into one firmware image.
2019-10-28 Move preliminary UART functions into some simple BSP files.
2019-10-28 Move the board initialization steps into a common 'board_init' BSP function. It would be nice to decouple the actual pin connections on the board from the functions like 'draw', 'check GPS location',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
2019-10-28 Improve main loop and display transfers. Instead of periodically refreshing, it now waits for a condition that merits a display update before performing one, and it avoids drawing to the framebuffer 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
    [interrupts.c, main.c]
2019-10-29 Fix 'tft_display' test firmware build.
    [main.c]
2019-10-29 Add a missing link to the 'mute' slide switch part in the bill of materials - whoops!
    [MotoMate_BoM.csv]
2019-10-29 Implement brightness control test menu. I really need to move the input handling out of the interrupt handlers...
2019-10-29 Move button-press logic out of interrupt handlers and into the 'application code' files.
2019-10-29 Start to outline a 'battery reading' test, and some minor formatting.
2019-10-29 Add ADC initialization and outline 'battery check' test.
2019-10-29 Implement basic 'battery check' test, add a menu selector to the audio test menu, and add a menu item for a future 'touch screen' test.
2019-10-30 Add autodocs for the 'global.h' file. It looks like it prints arrays with the post-preprocessor number of elements, but otherwise this seems promising.
2019-12-15 Update the QFP chip footprint to have longer pads for easier soldering. Simplify the audio amp circuit. Use a smaller power switch and put it closer to the power supply. Switch voltage regulators to 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
    [MotoMate.kicad_pcb, MotoMate.sch]
2019-12-15 Re-add the OSHW logo
    [MotoMate.kicad_pcb]
2019-12-15 Round PCB corners.
    [MotoMate.kicad_pcb]
2019-12-16 Update schematic for the new voltage regulator.
    [MotoMate.sch]
2019-12-16 Update bill of materials for the third (still untested) revision.
    [MotoMate_BoM.csv]
